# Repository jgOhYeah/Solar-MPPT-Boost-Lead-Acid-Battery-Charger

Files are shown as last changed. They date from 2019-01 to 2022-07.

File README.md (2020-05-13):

# Solar MPPT Boost Lead Acid Battery Charger
## A solar powered charger designed for charging lead acid batteries with the same or slightly higher voltage than the solar panel.

## About this project
The tracter is mainly used for mowing grass and does not get used much over the winter. As a result the battery in it has been known to be flat or very close to it by the time it is needed again when the grass starts growing. This charger was built to keep some charge in the battery so that the tractor would have a higher chance of starting when needed and hopefully extending the battery life of it by not letting it sit flat for months.

I built this charge controller mostly out of various parts I had access to that were lying around. The solar panel was from a solar powered water pump and actually outputted 12V as opposed to the 18V from a standared "12V" panel designed for charging lead acid batteries. The solar panel is probably in the range of 10W.

Because of this lower voltage, the battery did not charge when connected directly to the solar panel. Most regular solar charge controllers seem to be designed to run off an 18V solar panel to charge a 12V battery, allowing several volts to play with, whereas I needed a controller that would increase the voltage to charge the battery.

This charger tries to match the power output of the solar panel to the battery to get the most energy into it. It will also not let the battery get above a voltage (13.8v) as set by the variable resistor.

The charger has a boost regulator in it to allow solar panels of a lower voltage than the battery to charge it.

The microcontroller used for this is a [picaxe 08M2](http://www.picaxe.com/Hardware/PICAXE-Chips/PICAXE-08M2-microcontroller/). This is a small microcontroller that is very simple to program and can be programmed and updated "in the field."

The maximum power point tracking part of this is based off a version commonly designed and built for model solar vehicles competing in the [Australian-International Model Solar Vehicle Challenge](https://www.modelsolarchallenge.com.au/) and associated state events for matching the voltage produced by the solar panel to the voltage required by the motor at different stages during the race (stalled when the car is stopped, spinning fast when the car is at top speed) at the most power possible.

## Setting the maximum voltage to charge the battery to
Carefully adjust the potentiometer (white knob with Philips head screw) inside the box – it is quite sensitive. Measure the battery voltage carefully over the next while to check.

## Photos of the original installation
This has since removed as it is no longer required in this spot, but will be redeployed somewhere else at some stage.

The shed and tractor that the charger was used with and the controller mounted on its post.

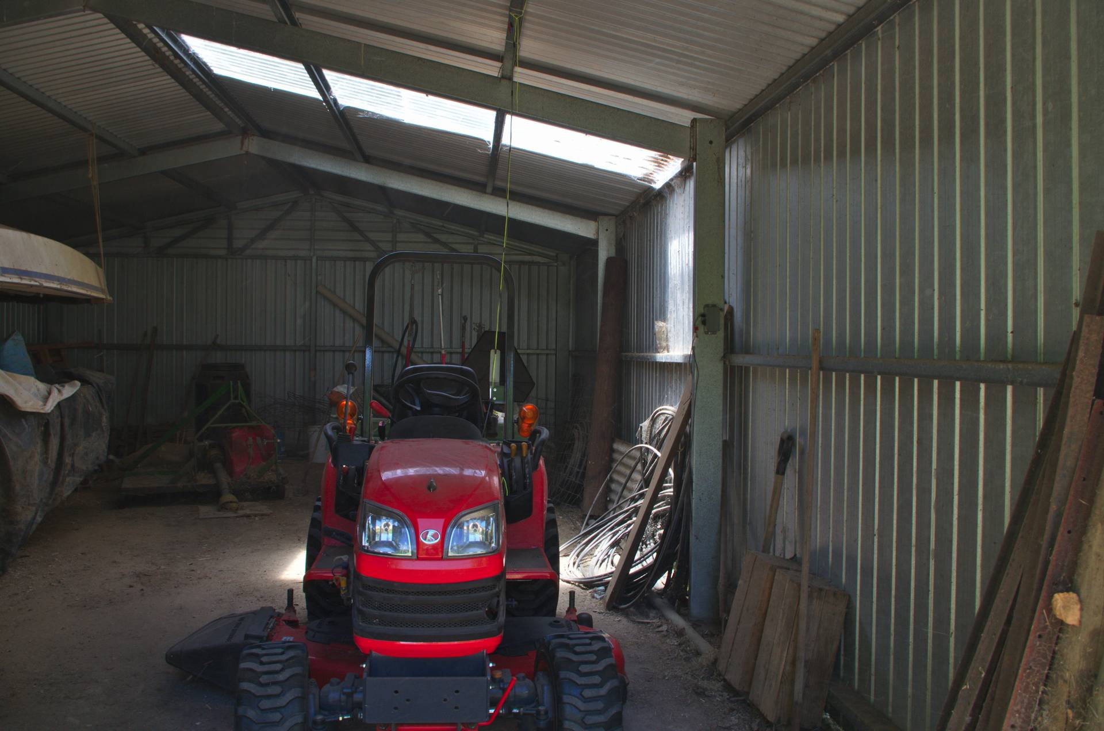
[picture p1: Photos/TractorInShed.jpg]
The shed and tractor that the charger was used with.

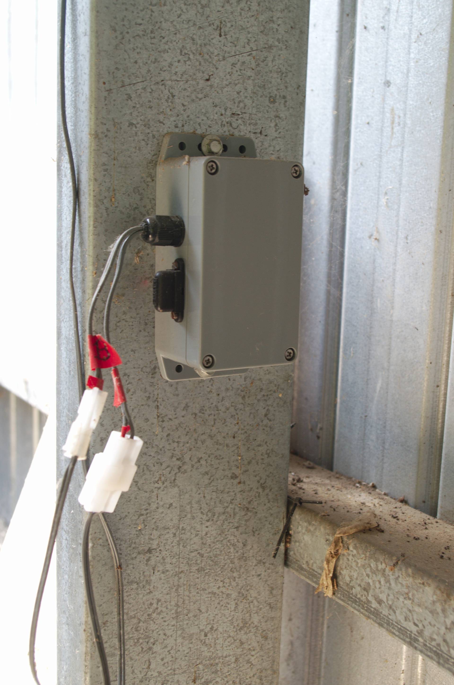
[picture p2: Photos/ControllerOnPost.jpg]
The controller on its post.


In case someone forgot to unplug the charger and drove off, a pair of bullet connectors were used to disconnect the wires. To stop them being unplugged in normal use, the wire from the rafters to the tractor is supported by a length of string that will break if pulled really hard to let the wires be unplugged.

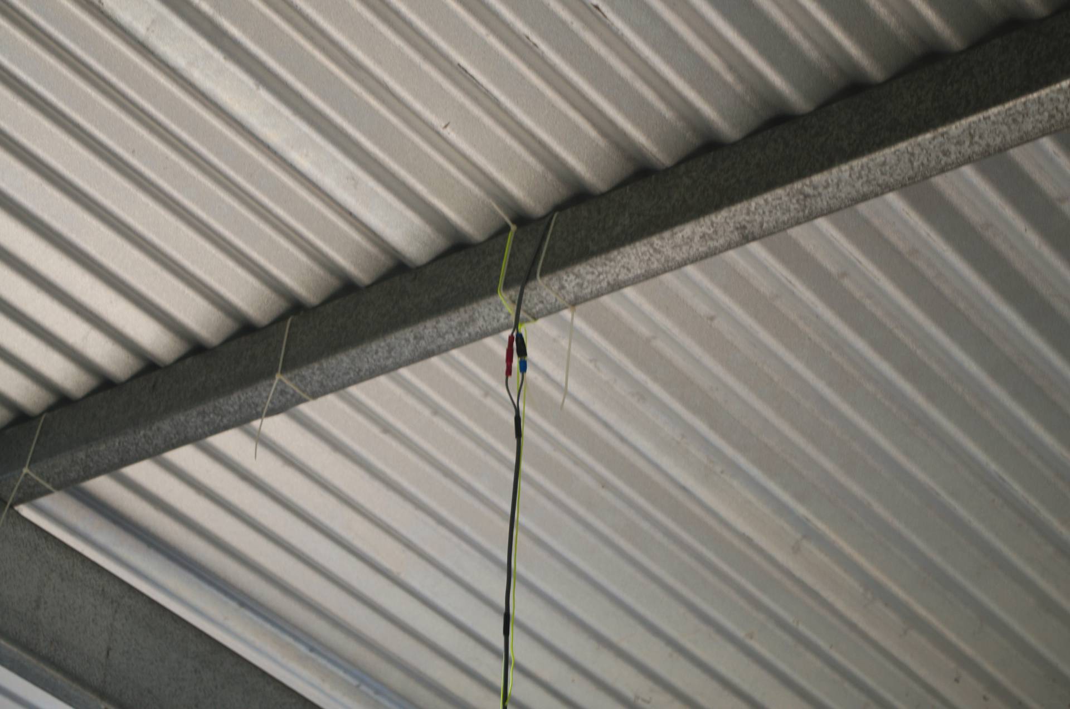
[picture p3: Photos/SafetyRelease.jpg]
Emergency safety release.

The connector on the tractor end.

Inside the controller with the lid removed.

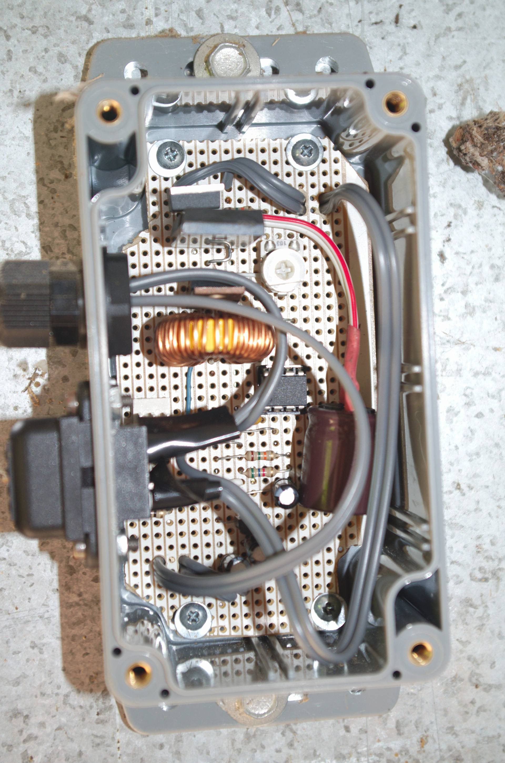
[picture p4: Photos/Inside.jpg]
Inside the controller with the lid removed.


## How it works
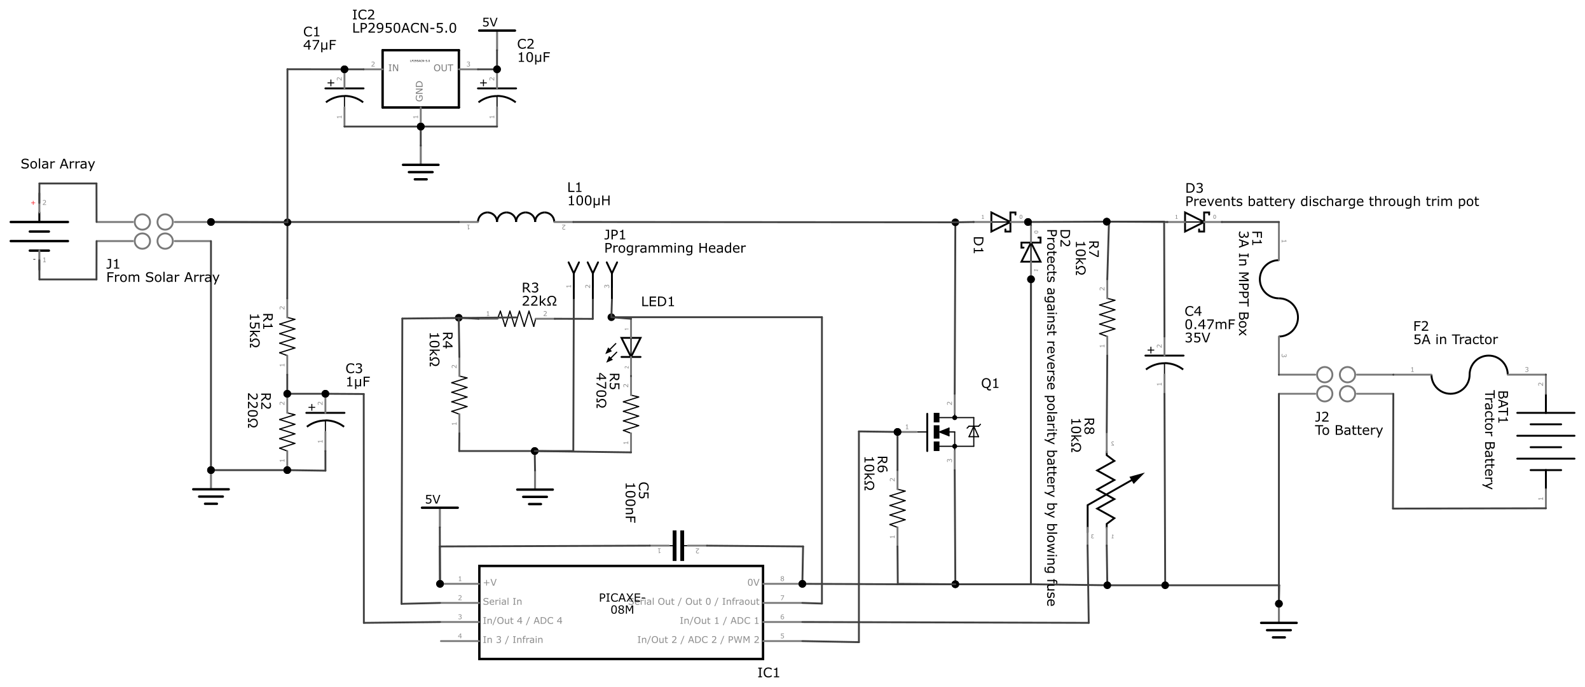
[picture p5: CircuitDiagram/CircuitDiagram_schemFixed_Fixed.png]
Circuit Diagram from /CircuitDiagram/CircuitDiagram_schemFixed_Fixed.png

The voltage regulator (IC2) provides power to a PICAXE 08M2 microcontroller (IC1). The PICAXE measures the solar panel open circuit voltage (or fairly close to it) through the voltage divider on the panel side (R1 and R2). It then multiplies this by 80% to get something fairly close the Maximum Power Point (MPP), where the voltage multiplied by the current produces the most power. This charger cannot measure current, so this is the quickest and easiest way of attempting to find it.

The chip will then put a Pulse Width Modulation (PWM) signal to turn the MOSFET on and off, which then draws and interrupts current in the inductor. This creates spikes in the voltage, which are fed through a diode (D1) into a capacitor(C4), where they are stored. The battery is charged through a second diode (D3). The PICAXE varies the duty cycle of the PWM signal to vary how much energy goes through the boost regulator to try to keep the solar panel voltage at the MPP as it determined previously.

To stop the battery from being overcharged, the chip measures the voltage being put into the battery and keeps the regulator at a constant voltage (13.8V) set by the variable resistor until either the voltage on the battery side falls to below ~13.1V or the solar panel voltage falls below its maximum power point, signalling that there is a load placed on the charger and it should start trying to get the most power that it can out of the solar panel.

The charger also stops charging for a few seconds once every 5 minutes to recalculate the MPP in case it has changed.
The LED (LED1) flashes on start up, when maximising and when sending serial data that a computer could pick up if one is connected. The LED also flashes when the battery is disconnected as it treats the storage capacitor as an extremely small battery and charges it so quickly that it spends most of its time maximising.

Serial communication is achieved with a standard PICAXE programming cable or similar (may require an adapter to convert from an audio jack to the 3 pin header (JP1)) and a serial terminal / reader set to 38400 baud, no parity, 8 data bits and one stop bit. I have been using a standared picaxe usb to serial converter programming cable, which I am pretty sure the signal is inverted (when most standared serial pins are high, the programming pins on a picaxe are low and when most standared serial pins are low, the programming pins on a picaxe are high) compared to a standared usb - serial converter or an arduino. 

This charger will not work properly with solar panels that have a significantly higher (more than a few volts) open circuit voltage than the battery as the charger has no way of actually completely disconnecting the battery and solar panel other than using diodes and relying on the battery voltage being higher or close enough that the solar panel cannot push current through it when the boost regulator is not running, possibly overcharging the battery and interfering with the way the charger works out the optimum voltage to get the most power from the panel (the Maximum Power Point, or MPP). If you want to use this for higher voltage panels, you will need to convert it to a buck regulator.

## Notes
I used this calculator to estimate the correct size for the inductor and other components involved with increasing the voltage, as well as the duty cycles for the pwm to run at: [https://learn.adafruit.com/diy-boost-calc](https://learn.adafruit.com/diy-boost-calc).

**Please note that I built this a while ago and some of the files / documentation may not be up to date or missing. I have also updated the firmware in the controller a bit and am not quite sure which documentation suits which firmware revision. I think it is pretty close now.*

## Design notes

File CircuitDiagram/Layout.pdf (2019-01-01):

# PEBBLE - Picaxe Electronic Bread Board Layout Emulator - V3.0e

Drag components from the Menu to Breadboard, then Right-Click component to edit (For FF >=1.5 only)WA55 | menu location control Gnd Solar + - | Programming DIODE

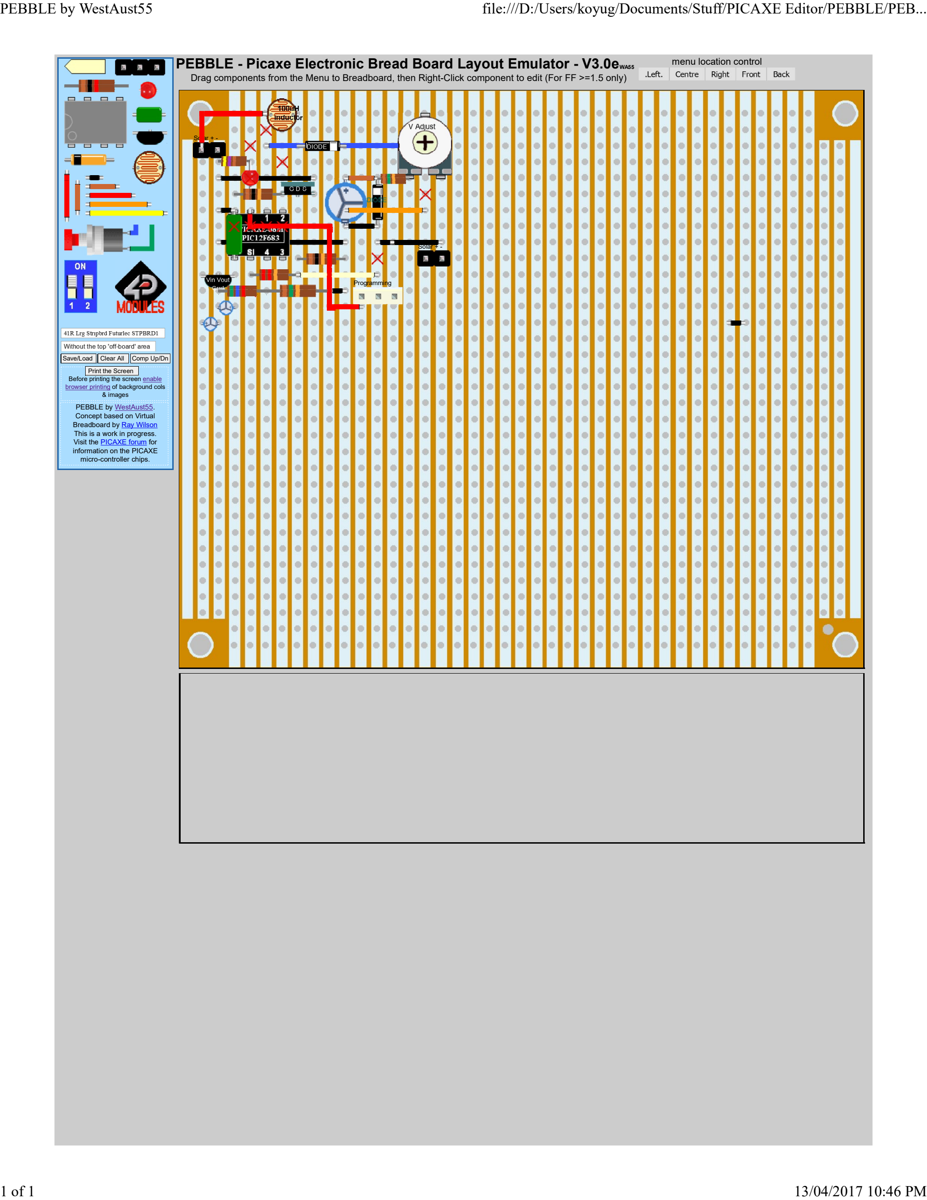
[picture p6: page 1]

PEBBLE by WestAust55. Concept based on Virtual Breadboard by Ray Wilson This is a work in progress. Visit the PICAXE forum for information on the PICAXE micro-controller chips. Before printing the screen enable

browser printing of background cols & images Save/Load | Clear All | Comp Up/Dn Print the Screen

100uH
inductor | Solar + -
PEBBLE by WestAust55 | file:///D:/Users/koyug/Documents/Stuff/PICAXE Editor/PEBBLE/PEB...
1 of 1 | 13/04/2017 10:46 PM

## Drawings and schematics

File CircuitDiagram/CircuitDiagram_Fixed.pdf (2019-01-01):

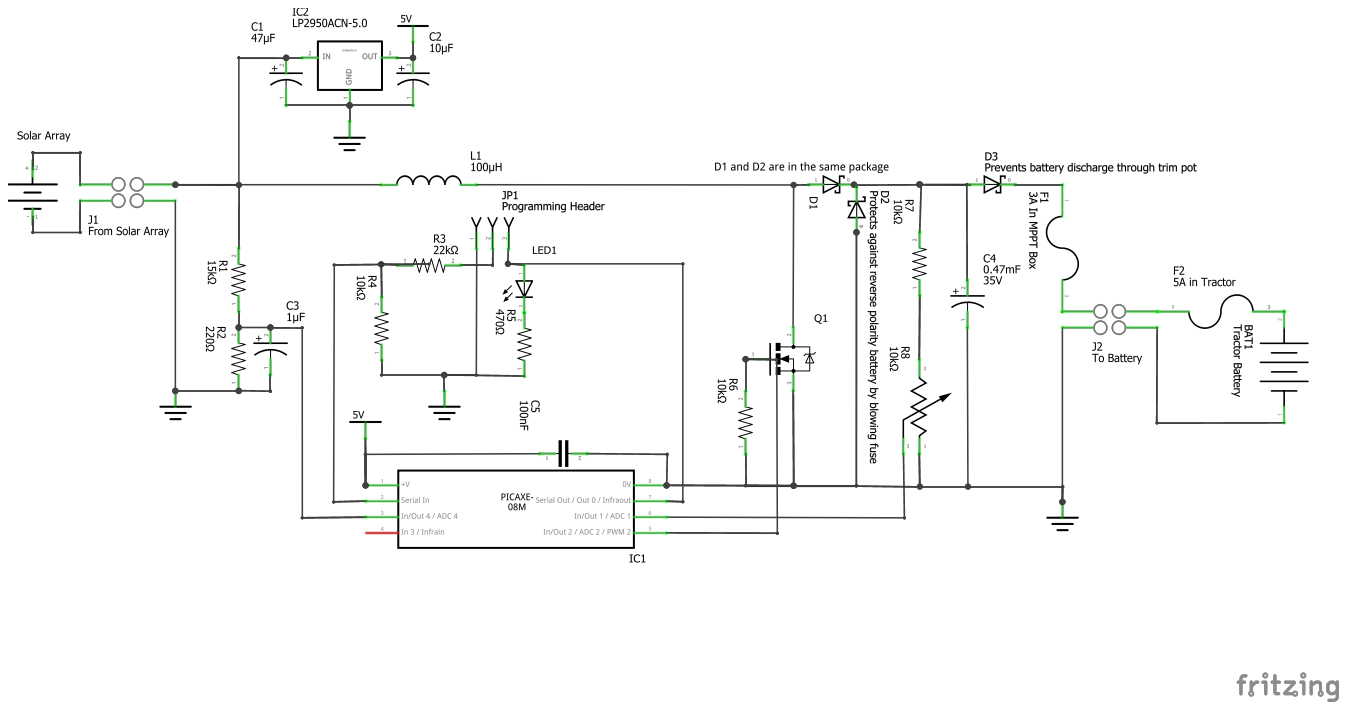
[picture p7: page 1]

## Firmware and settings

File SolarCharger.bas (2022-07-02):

' Solar powered boost battery charger with approximated maximum powerpoint
' tracking.
' Aims to keep the solar panel voltage at ~80% OCV, or can be set to a fixed
' value or some other fraction. See accompanying documentation for more
' information.
'
' Written by Jotham Gates, based on a MPPT design used in model solar vehicle
' races (https://www.modelsolar.org.au/).
' Created 2017
' Modified 02/07/2022

#picaxe 08m2
#no_data

#define VERSION "v2.1"

' pins
symbol PIN_LED = c.0
symbol PIN_VOLTS_OUT = c.1
symbol PIN_MOSFET = c.2
symbol PIN_VOLTS_IN = c.4

' variables
symbol debug_mode = bit0
symbol fixed_mpp_voltage = bit1
symbol bulk_charge = bit2
symbol battery_voltage = b1
symbol solar_voltage = b2
symbol battery_target_voltage = b3
symbol tmpwd0 = w2
symbol tmpwd0l = b4
symbol tmpwd0h = b5
symbol mpp_voltage_numerator = b6
symbol mpp_voltage_denominator = b7
symbol led_on_threshlod = b8 ' Solar voltage at which the LED will turn on in float mode.
symbol previous_time = w10
symbol debug_count = w11
symbol current_duty = w12
symbol mpp_voltage = w13

' EEPROM Addresses
#define EEPROM_MPP_VOLTAGE_MODE 0
#define EEPROM_MPP_FIXED_VOLTAGE 1
#define EEPROM_MPP_NUMERATOR 2
#define EEPROM_MPP_DENOMINATOR 3

#define ADAPTIVE 0
#define FIXED 1

' constants' ' 
#define DUTY_MIN 0 ' 0% duty cycle at 4MHz clock at 15094Hz
#define DUTY_MAX 265 ' 50% duty cycle at 4MHz clock at 15094Hz
#define BAT_MAX 145 ' 14.4 - adjust pot to be this
#define BAT_FLOAT 138 ' 13.8 - voltage to hold for float charging.
#define BAT_MIN 126 ' Voltage to reenter bulk charging when below this.
#define BAT_MIN_LOCKOUT_TIME 60 ' Must have been running for 30s since last mppt before the under voltage can be recognised.
#define OVER_VOLTAGE 180 ' If over this voltage, cut of QUICK! - In case the load is suddenly reduced (battery unplugged)
#define DEBUG_EVERY 800
#define LED_ON_OFFSET 3 ' If solar_voltage > mpp_voltage + LED_ON_OFFSET, then led on, else off in float mode.

init:
	setfreq m32 ' 38400 Baud
	sertxd("Solar boost battery charger ", VERSION , cr, lf, "Jotham Gates, Compiled ", ppp_date_uk, cr, lf, "For more info, go to https://github.com/jgOhYeah/Solar-MPPT-Boost-Lead-Acid-Battery-Charger/", cr, lf)
	' Retrieve and print settings
	read EEPROM_MPP_VOLTAGE_MODE, fixed_mpp_voltage
	if fixed_mpp_voltage = FIXED then
		' Fixed voltage
		read EEPROM_MPP_FIXED_VOLTAGE, mpp_voltage_numerator
		sertxd("Fixed MPP Voltage. Set to ", #mpp_voltage_numerator, cr, lf)
	else
		' Adaptive voltage
		read EEPROM_MPP_NUMERATOR, mpp_voltage_numerator
		read EEPROM_MPP_DENOMINATOR, mpp_voltage_denominator
		if mpp_voltage_numerator = 0 or mpp_voltage_denominator = 0 then
			' Default EEPROM values from the factory. Load the defaults.
			sertxd("EEPROM Memory seems to have not been set. Setting defaults.")
			write EEPROM_MPP_NUMERATOR, 8
			write EEPROM_MPP_DENOMINATOR, 10
			goto reset_with_msg

		endif
		sertxd("Adaptive MPP Voltage. Set to OCV*", #mpp_voltage_numerator, "/", #mpp_voltage_denominator, cr, lf)

	endif

	' Debug mode and settings
	debug_mode = 0
	sertxd("Press:", cr, lf, "  - 'p' to print often", cr, lf, "  - 'f' for fixed mpp voltage mode", cr, lf, "  - 's' to set fixed mpp target voltage", cr, lf, "  - 'a' for adaptive mpp voltage mode (mpp voltage = OCV * numerator / denominator", cr, lf, "  - 'n' for numerator", cr, lf, "  - 'd' for denominator", cr, lf)
	serrxd[32000, continue_init], tmpwd0l
	select tmpwd0l
		case "p"
			sertxd("Enabling debug mode", cr, lf)
			debug_mode = 1

		case "f"
			sertxd("Setting fixed mode", cr, lf)
			write EEPROM_MPP_VOLTAGE_MODE, FIXED
		
		case "s"
			sertxd("Enter the voltage: ")
			serrxd #tmpwd0l
			write EEPROM_MPP_FIXED_VOLTAGE, tmpwd0l
			sertxd(#tmpwd0l, cr, lf, "Set.", cr, lf)

		case "a"
			sertxd("Setting adaptve mode", cr, lf)
			write EEPROM_MPP_VOLTAGE_MODE, ADAPTIVE

		case "n"
			sertxd("Enter the numerator: ")
			serrxd #tmpwd0l
			write EEPROM_MPP_NUMERATOR, tmpwd0l
			sertxd(#tmpwd0l, cr, lf, "Set.", cr, lf)

		case "d"
			sertxd("Enter the denominator: ")
			serrxd #tmpwd0l
			write EEPROM_MPP_DENOMINATOR, tmpwd0l
			sertxd(#tmpwd0l, cr, lf, "Set.", cr, lf)
		
		else
			sertxd("'", tmpwd0l, "' Not recognised", cr, lf)
	endselect
	if debug_mode = 0 then reset_with_msg

continue_init:
	reconnect
	sertxd("Continuing startup", cr, lf)
	high PIN_LED
	pause 4000
	gosub set_bulk_charge
	readadc PIN_VOLTS_IN, solar_voltage
	sertxd("Initial OCV: ", #solar_voltage, cr, lf)
	current_duty = DUTY_MIN
	pwmout pwmdiv4, PIN_MOSFET, 132, current_duty
	gosub mpp
	
main:
	' Read voltages
	readadc PIN_VOLTS_IN, solar_voltage
	readadc PIN_VOLTS_OUT, battery_voltage

	' Cut of quickly if massivly over voltage
	if battery_voltage >= OVER_VOLTAGE then
		current_duty = DUTY_MIN
		pwmduty PIN_MOSFET, current_duty ' Take action before printing
		sertxd("Overvoltage scram occurred", cr, lf)
	endif

	' Calculate and set the new duty cycle
	if solar_voltage < mpp_voltage or battery_voltage > battery_target_voltage then
		if current_duty > DUTY_MIN then
			current_duty = current_duty - 1
		endif
	endif
	if solar_voltage > mpp_voltage and battery_voltage < battery_target_voltage then
		if current_duty < DUTY_MAX then
			current_duty = current_duty + 1
		endif
	endif
	pwmduty PIN_MOSFET, current_duty

	' Debugging
	if debug_mode = 1 then gosub debug_charger

	' Re calibrate mpp every 300 seconds (time increment every 0.5 seconds at 32MHz
	if time > 600 then gosub mpp

	' State machine for charging
	' When started or if battery voltage ever falls below 12.6V, charge up to 14.3V.
	' When 14.3V is reached, hold at 13.8V.
	if bulk_charge = 1 then
		if battery_voltage >= BAT_MAX then gosub set_float_charge
		' Flash the led often
		if time != previous_time then
			toggle PIN_LED
			previous_time = time
		endif
	else
		if battery_voltage < BAT_MIN and time > BAT_MIN_LOCKOUT_TIME then gosub set_bulk_charge
		' LED is on when voltage limited, LED is off when at mpp
		if solar_voltage > led_on_threshlod then
			high PIN_LED
		else
			low PIN_LED
		endif
	endif
	goto main

mpp:
	if fixed_mpp_voltage = ADAPTIVE then
		' Use the fraction of OCV rule.
		sertxd("Adaptive MPPT. Maximising", cr, lf)
		current_duty = DUTY_MIN
		pwmduty PIN_MOSFET, current_duty
		high PIN_LED
		pause 20000
		low PIN_LED
		pause 20000
		readadc PIN_VOLTS_IN, mpp_voltage
		sertxd("OCV: ", #mpp_voltage)
		mpp_voltage = mpp_voltage * mpp_voltage_numerator / mpp_voltage_denominator ' MPP is roughly 80% of OCV
		sertxd("\tMPP: ", #mpp_voltage, cr, lf, cr, lf)
	else
		' Use a fixed value in EEPROM.
		sertxd("Fixed MPPT at ", #mpp_voltage_numerator, cr, lf)
		mpp_voltage = mpp_voltage_numerator
	endif

	led_on_threshlod = mpp_voltage + LED_ON_OFFSET
	gosub reset_time
	return

reset_time:
	disabletime
	time = 0
	enabletime
	return

reset_with_msg:
	sertxd("Resetting so changes take effect.", cr, lf, cr, lf)
	reset
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

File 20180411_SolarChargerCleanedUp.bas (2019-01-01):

'Solar powered boost battery charger with maximum powerpoint tracking
'Revision 2.0 - 11 April 2018
'See accompanying documentation for more information
'Jotham Gates 2017 - 2018

'pins
symbol led = c.0
symbol voltsOut = c.1
symbol mosfet = c.2
symbol voltsIn = c.4

'variables
symbol batteryVoltage = b0
symbol solarVoltage = b3
symbol currentDuty = w12
symbol mppVoltage = w13

'constants
symbol dutyMin = 0 '0% duty cycle at 4MHz clock at 15094Hz
symbol dutyMax = 265 '50% duty cycle at 4MHz clock at 15094Hz
symbol batMax = 140 '13.8 - adjust pot to be this
symbol batMin = 137 '~13.1 - voltage at which to drop back into maximising
symbol overVoltage = 200 'If over this voltage, cut of QUICK! - In case the load is suddenly reduced (battery unplugged)
init:
	setfreq m32
	sertxd("Started", 13, 10)
	high led
	pause 16000
	low led
	pause 24000
	readadc voltsIn, solarVoltage
	sertxd("Initial OCV: ", #solarVoltage, 13, 10)
	currentDuty = dutymin
	pwmout pwmdiv4, mosfet, 132, currentDuty
	gosub mpp
	
main:
	'Maximum Power Point Tracker part
	readadc voltsIn, solarVoltage
	if solarVoltage < mppVoltage then
		if currentDuty > dutyMin then
			currentDuty = currentDuty - 1
		endif
	endif
	if solarVoltage > mppVoltage then
		if currentDuty < dutyMax then
			currentDuty = currentDuty + 1
		endif
	endif
	
	'Battery monitoring part
	readadc voltsOut, batteryVoltage
	if batteryVoltage > batMax then gosub batCharged
	'Change MOSFET duty cycle
	pwmduty mosfet, currentDuty
	'Re calibrate mpp every 300 seconds (time increment every 0.5 seconds at 32MHz
	if time > 600 then gosub mpp
	goto main
batCharged:
	'Send a message to say battery charged
	sertxd("Battery Charged", 13, 10)
	'repeat until solar panel voltage is below mpp or the battery voltage has dropped sufficiently
	high led
	do
		'Re calibrate mpp every 300 seconds (time increment every 0.5 seconds at 32MHz
		if time > 600 then gosub mpp
		'Constant voltage part
		readadc voltsOut, batteryVoltage
		if batteryVoltage > batMax then
			if currentDuty > dutyMin then
				currentDuty = currentDuty - 1
			endif
		endif
		if batteryVoltage < batMax then
			if currentDuty < dutyMax then
				currentDuty = currentDuty + 1
			endif
		endif
		'Cut of quickly if massivly over voltage
		if batteryVoltage >= overVoltage then
			currentDuty = dutyMin
		endif
		pwmduty mosfet, currentduty
		readadc voltsIn, solarVoltage
	loop while solarVoltage >= mppVoltage and batteryVoltage >= batMin
	low led
return
mpp:
	sertxd("Maximising",13,10)
	currentDuty = dutyMin
	pwmduty mosfet, currentDuty
	high led
	pause 20000
	low led
	pause 20000
	readadc voltsIn, mppVoltage
	sertxd("OCV: ", #mppVoltage)
	mppVoltage = mppVoltage * 8 / 10 'MPP is roughly 80% of OCV
	sertxd("\tMPP: ", #mppVoltage, 13, 10, 13, 10)
	gosub resetTime
return
resetTime:
	disabletime
	time = 0
	enabletime
return

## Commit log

2019-01-01 Adding files and md
    [CircuitDiagram.fzz, Efficiency.xlsx]
2022-07-02 All voltage regulation occurs in the one loop now.
2022-07-02 MPP Mode swapping fixed, running on electri fence
    [SolarCharger.bas]
